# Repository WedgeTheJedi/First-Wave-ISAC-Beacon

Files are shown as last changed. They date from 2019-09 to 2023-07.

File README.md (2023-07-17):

# First-Wave-ISAC-Beacon
The First Wave ISAC Beacon is a recreation of the shoulder mounted radio worn by players in Tom Clancy's The Division video games. This version is modified from the 3D model work of 2 other authors (attributes in the guides).  It has fully functioning audio and visual effects from The Division 2. This version of the ISAC beacon also has multiple modes and features accessed by the buttons on the unit including:

- Startup boot sequence effect and audio
- 4 SHD skills from in-game with sound and visual effects
- World notifications as heard in-game that can be played manually, or automatically
- Dark Zone Mode that changes world notifications to ones specifically heard in the Dark Zone
- Rogue protocol - go rogue and turn the ISAC light ring RED while in the Dark Zone
- Volume control (especially to increase volume for cosplay at conventions)
- ISAC light ring 'chatter' effect when ISAC is talking

See the User Guide for information on how to access these features.

Here is a video showcasing the effects, however the camera doesn’t show the light ring effects as well as I had hoped (especially the light ring turning red during Rogue mode). 
https://vimeo.com/362583784

To achieve the effects of the First Wave ISAC Beacon, I designed and created a custom circuit board that simplifies assembly and soldering.  Also developed custom Arduino software to run the device and effects.  

See the Assembly Guide for a full list of parts and components as well as additional instructions and advice.

Latest updates:
2023-07-17 - Was working on building a few of these and found that the latest libraries and Arduino IDE compiler have improved performance.  This lead to timing issues with my older code which I believe I have fixed.  I also refactored a lot of the code including button state handling to be more precise and avoid the code treating a single click as multiple clicks.
             Known issue with current build: Rarely when you either enter or exit Rogue status the program will stop responding to further button clicks.  If this happens simply reboot the device, or add a but longer delay() at the end of the enter and exit Rogue functions.

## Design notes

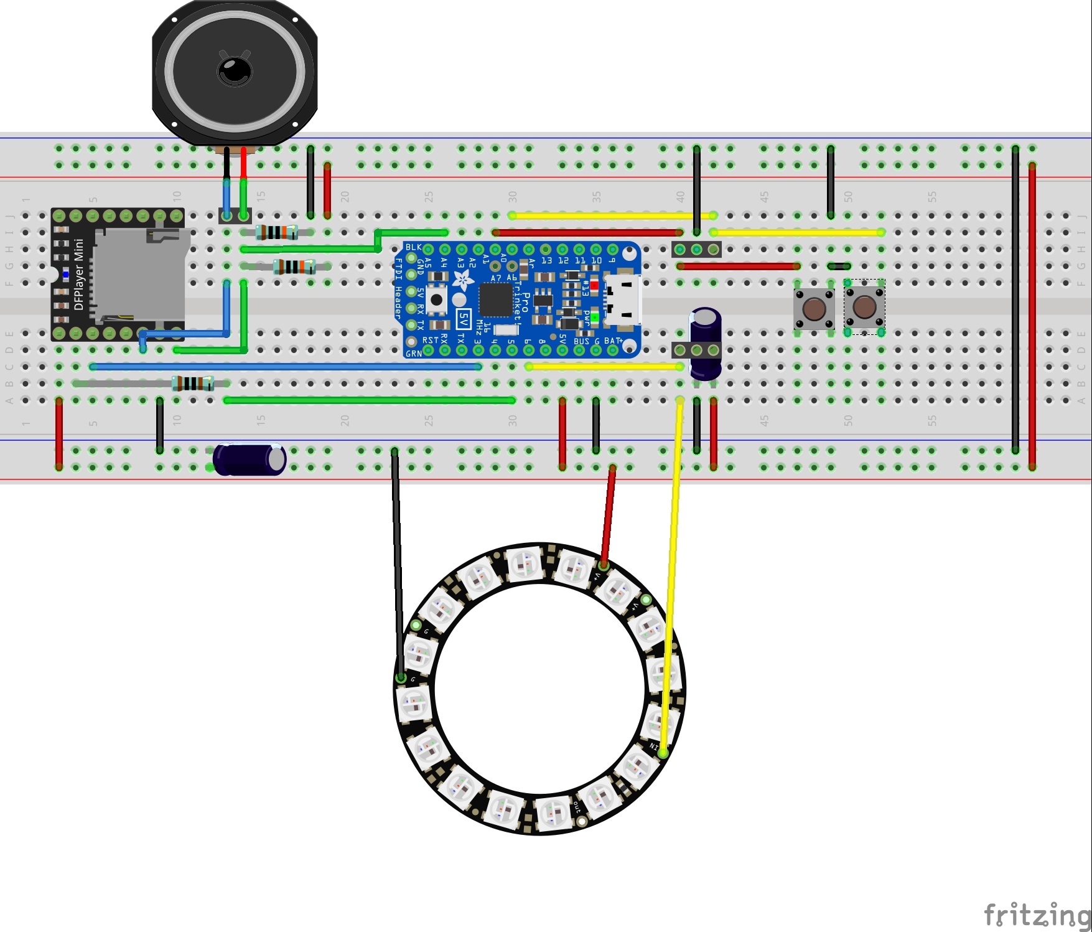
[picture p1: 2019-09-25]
PCB Files/FirstWaveISACBeacon_PCBv2.6_bb.jpg

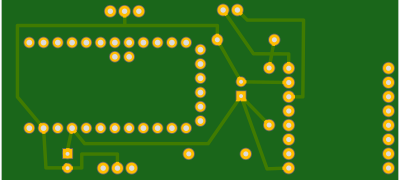
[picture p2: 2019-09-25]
PCB Files/PCB_Preview_Bottom.png

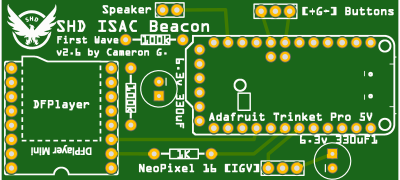
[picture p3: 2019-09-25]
PCB Files/PCB_Preview_top.png

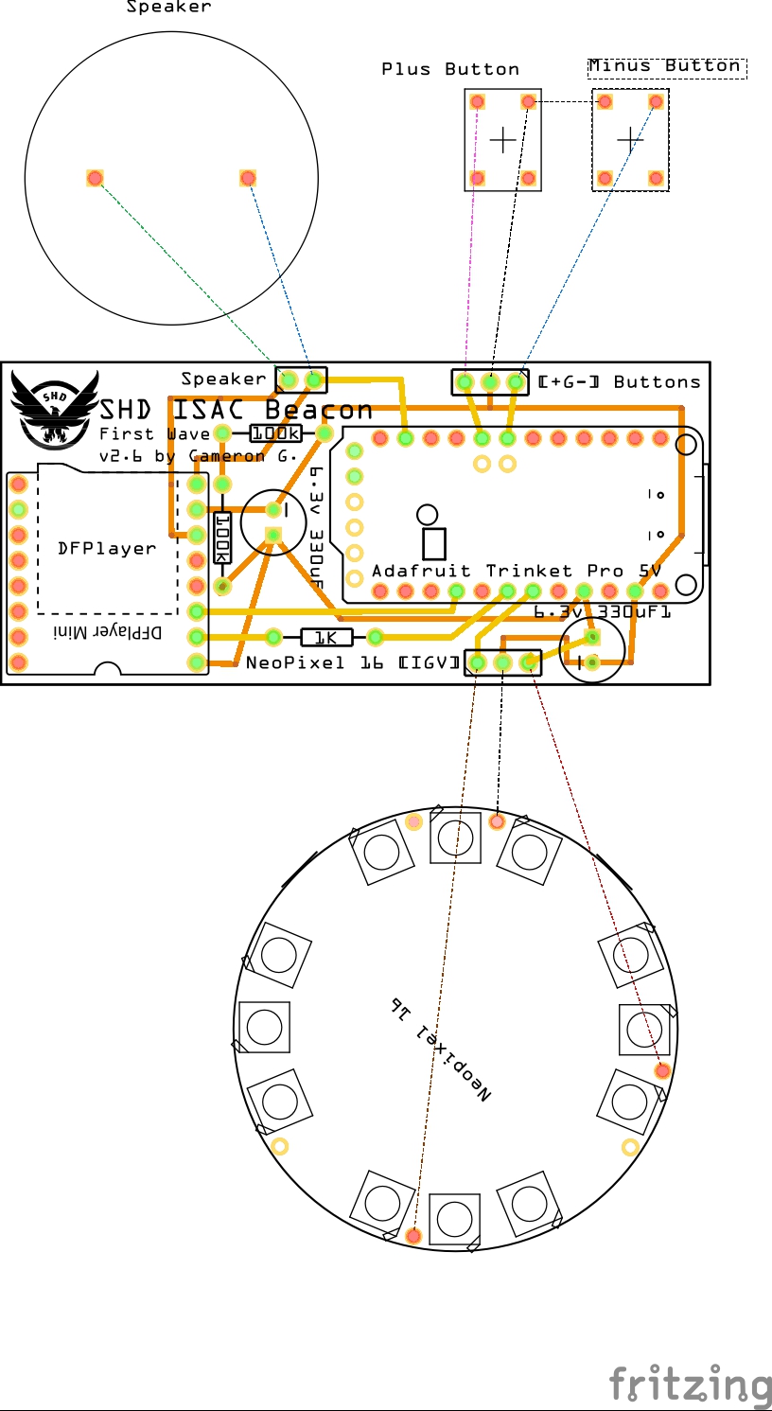
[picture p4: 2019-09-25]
PCB Files/FirstWaveISACBeacon_PCBv2.6_pcb.jpg

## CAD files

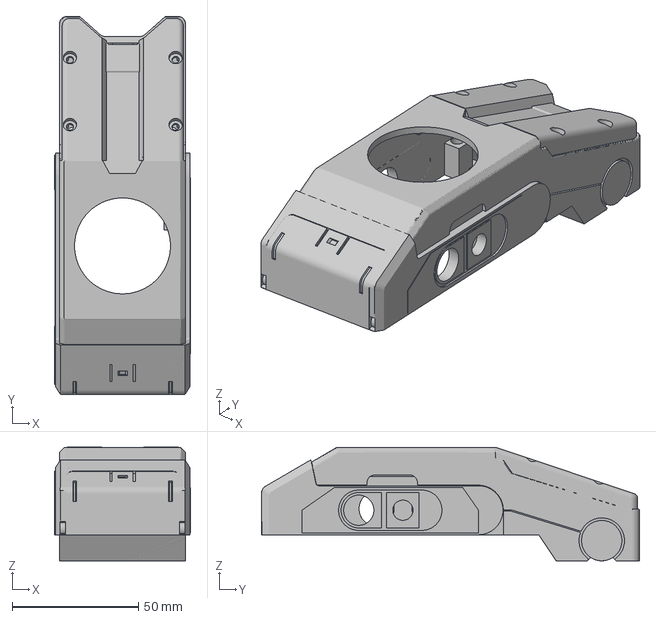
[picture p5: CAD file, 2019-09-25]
3D Print Files/FirstWave_Full_Frame.3mf
54.0 x 149.9 x 45.0 mm

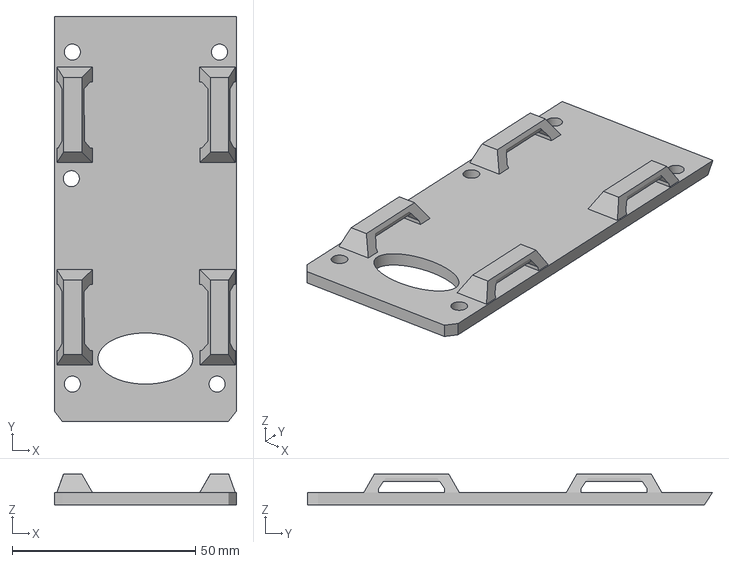
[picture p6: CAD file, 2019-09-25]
3D Print Files/FirstWave_Baseplate_w_Loops.3mf
49.7 x 110.4 x 8.39 mm

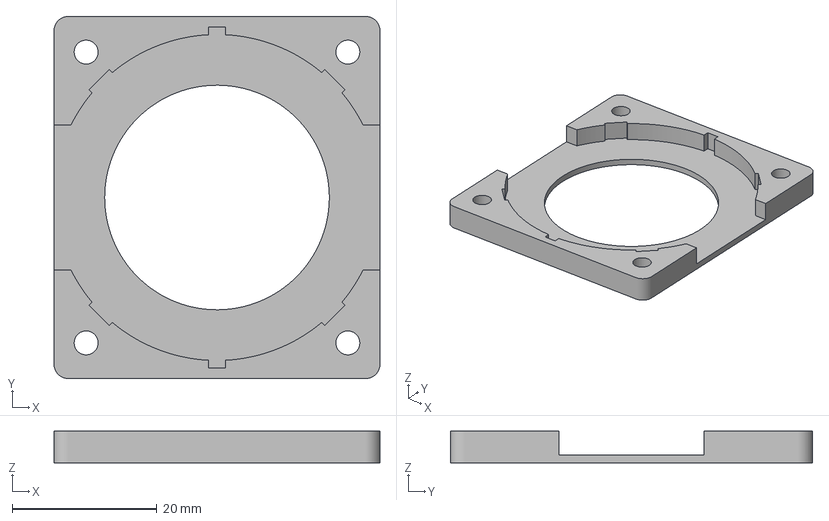
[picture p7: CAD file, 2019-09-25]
3D Print Files/FirstWave_Neopixel_Base.3mf
45.0 x 50.0 x 4.40 mm

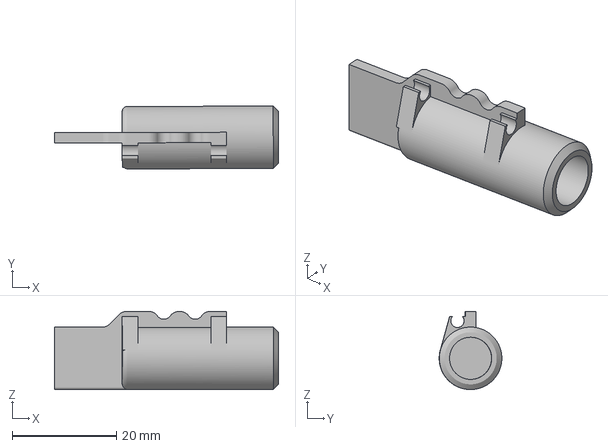
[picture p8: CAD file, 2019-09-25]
3D Print Files/FirstWave_Antenna_Bottom.3mf
43.0 x 12.0 x 15.0 mm

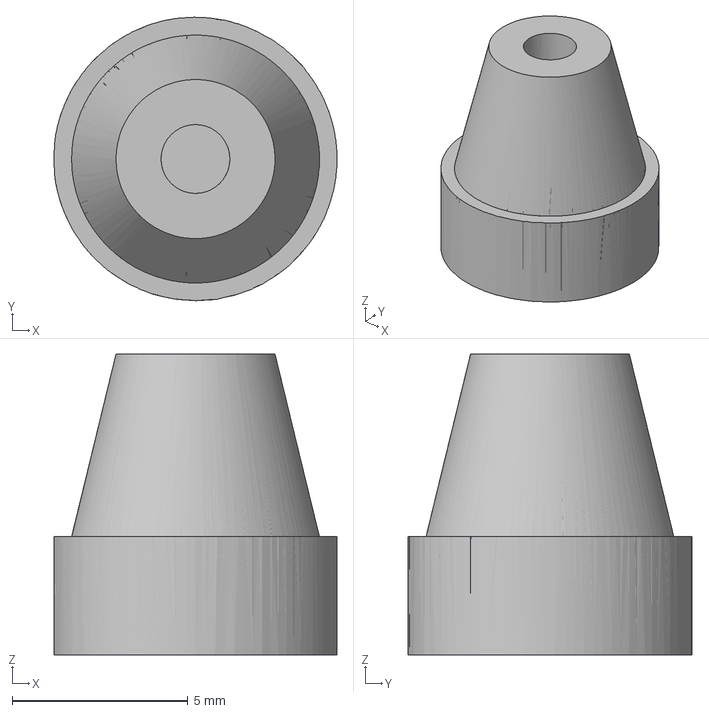
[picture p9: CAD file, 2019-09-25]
3D Print Files/FirstWave_CablePort.3mf
8.05 x 8.08 x 8.57 mm

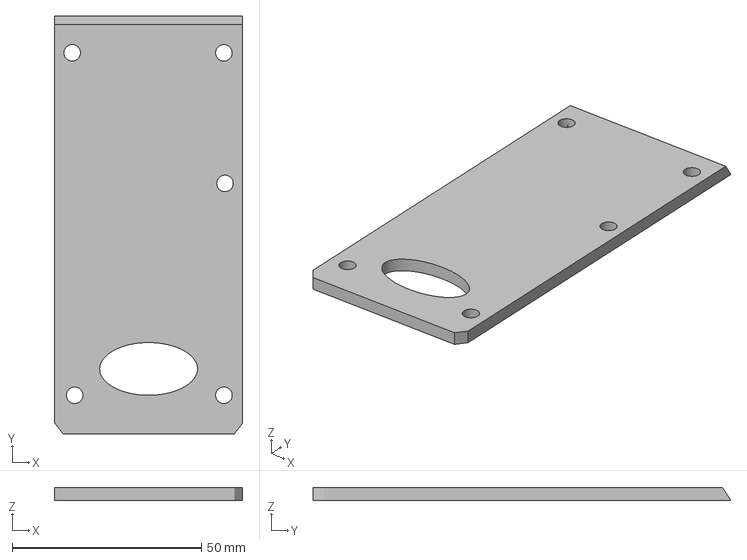
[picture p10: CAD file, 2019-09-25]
3D Print Files/FirstWave_Baseplate_w_Clip.3mf
49.7 x 110.4 x 3.39 mm

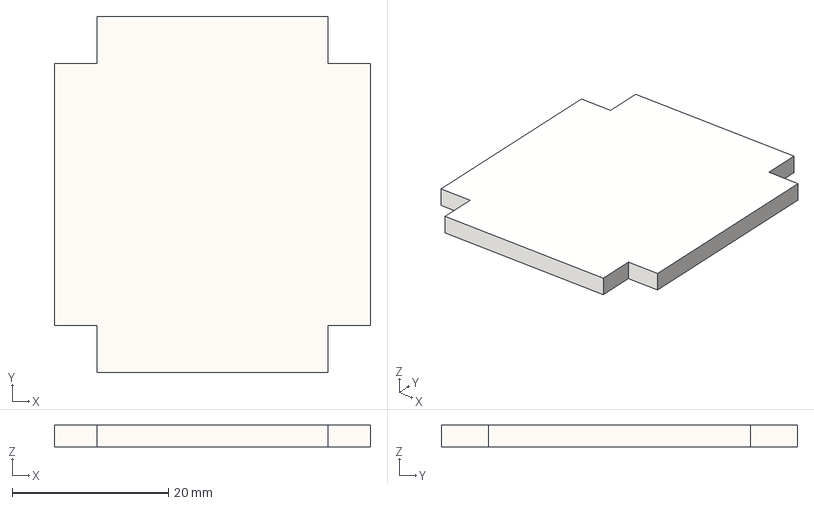
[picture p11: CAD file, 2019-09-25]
3D Print Files/FirstWave_LED_Difusser_Clear_Filament.3mf
40.4 x 45.5 x 2.80 mm

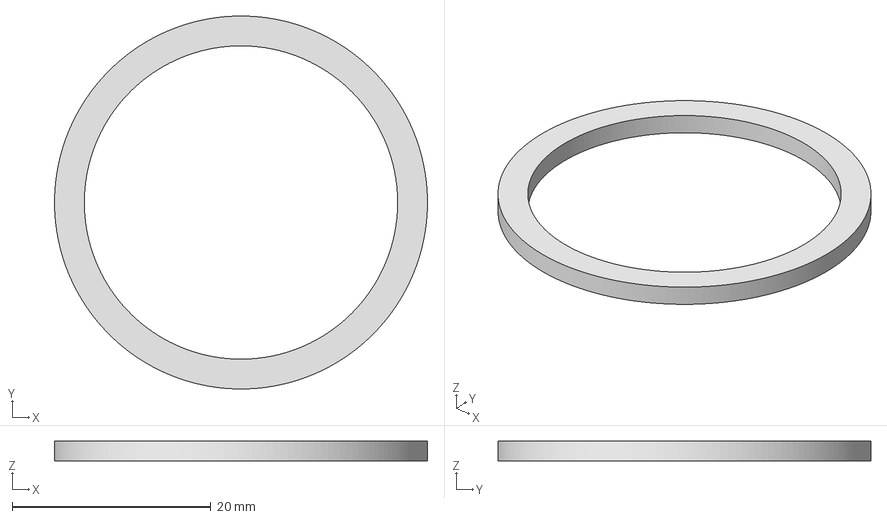
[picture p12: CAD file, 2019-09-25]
3D Print Files/FirstWave_LED_Ring_Clear_Filament.3mf
37.5 x 37.5 x 2.00 mm

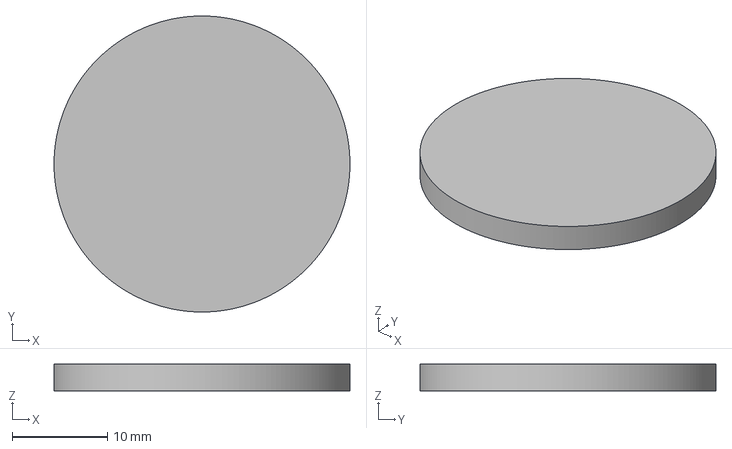
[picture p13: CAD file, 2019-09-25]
3D Print Files/FirstWave_LED_Ring_mid_Plate.3mf
31.0 x 31.0 x 2.80 mm

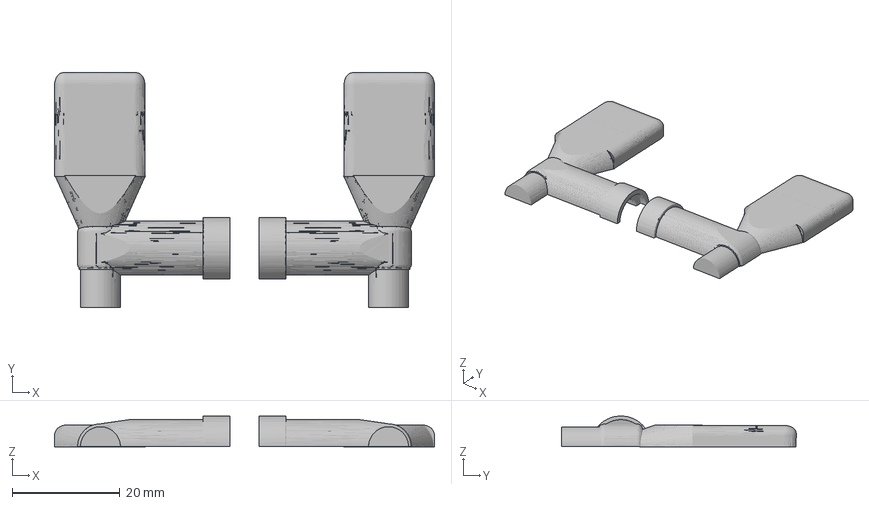
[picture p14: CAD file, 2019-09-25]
3D Print Files/FirstWave_Antenna_Frame_w_Bolt_Support.3mf
70.5 x 43.5 x 5.71 mm

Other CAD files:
3D Print Files/STLs/FirstWave_Antenna_Bottom.STL
3D Print Files/STLs/FirstWave_Antenna_Frame_w_Bolt_Support.stl
3D Print Files/STLs/FirstWave_Baseplate_w_Clip.stl
3D Print Files/STLs/FirstWave_Baseplate_w_Loops.stl
3D Print Files/STLs/FirstWave_CablePort.stl
3D Print Files/STLs/FirstWave_Full_Frame.stl
3D Print Files/STLs/FirstWave_LED_Difusser_Clear_Filament.STL
3D Print Files/STLs/FirstWave_LED_Ring_Clear_Filament.STL
3D Print Files/STLs/FirstWave_LED_Ring_mid_Plate.STL
3D Print Files/STLs/FirstWave_Neopixel_Base.stl

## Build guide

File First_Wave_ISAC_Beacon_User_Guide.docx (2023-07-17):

# First Wave ISAC Beacon User Guide

By Cameron G.

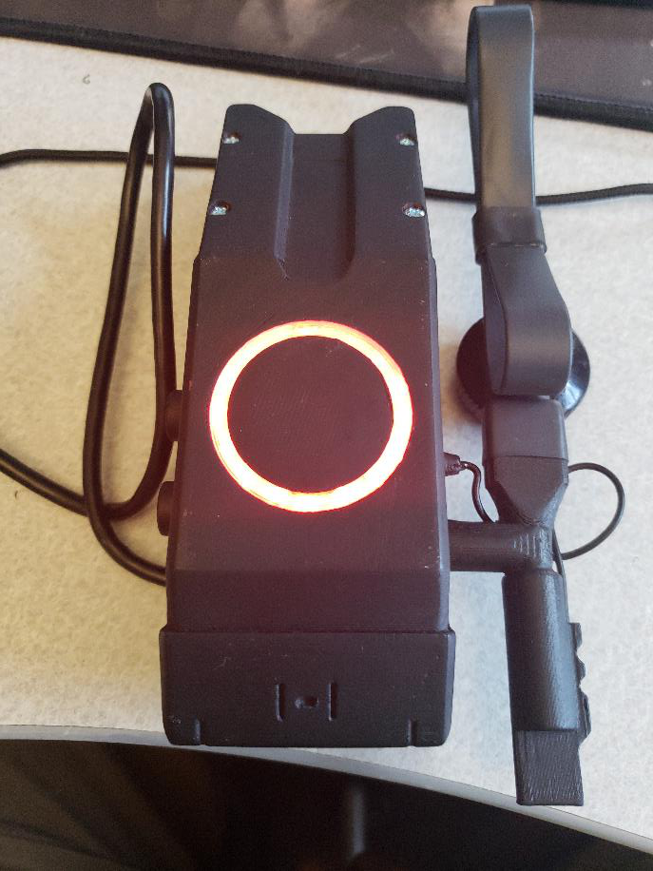
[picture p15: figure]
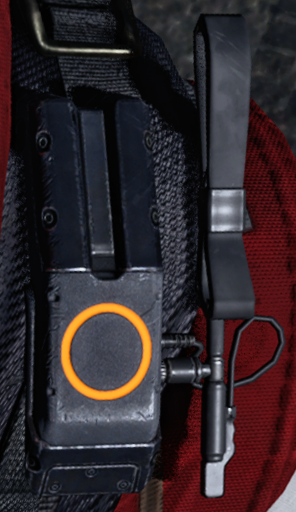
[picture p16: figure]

The following is a guide to using the First Wave ISAC Beacon which is a replica of the Integrated Systems Analytic Computer (ISAC) shoulder radio beacon used by SHD Agents in Tom Clancy’s: The Division franchise. The intended purpose of the First Wave ISAC Beacon is to give fans of The Division a way to show off their love of the game through Cosplay at conventions or just wearing it around for fun. Although it took a lot of time and effort to develop the software and circuitry used in the First Wave version of the ISAC beacon, I saw it as a challenge to do something fun and learn new skills along the way. I hope you enjoy and are excited about the result as I am.

-Cameron G.

# Acknowledgements

I followed the work done by two authors on thingiverse.com and their versions of the ISAC radio beacon. Building off the fine work they did, I created and modified specific parts to fit the functionality of this version and simplify the construction process. I also initially used some of the audio that was provided by a reddit user. I want to acknowledge their efforts and files that gave me a good starting point for my own version.

MZD471 (https://www.thingiverse.com/MZD471) - Tom Clancy's The Division Functional Comms Module (https://www.thingiverse.com/thing:1327053)
3D model used as the base of the First Wave version. Modified housing for buttons, shorter radio antenna, and edited to be one printed piece for the top and one separate piece for bottom.

guido666 (https://www.thingiverse.com/guido666) - The Division - Shoulder Beacon v3 (https://www.thingiverse.com/thing:1411233)
Parts of the 3D antenna were used to crate my own version and well as the code provided for learning how to work with the NeoPixel ring.

u/KlotziDotCom (https://www.reddit.com/user/KlotziDotCom/) - Hello Agents, here are some Division 2 ISAC Sound Files! (https://www.reddit.com/r/thedivision/comments/bwwdh8/hello_agents_here_are_some_division_2_isac_sound/)
Initial audio files I played with. I eventually recorded, edited, and normalized new audio files myself, but some of Klotzi’s work is still in the audio files used.

# Functionality and Controls

The ISAC beacon only has two buttons (+) and (-) on the left side. The following effects, modes, and functionality can be accessed by using these two buttons.

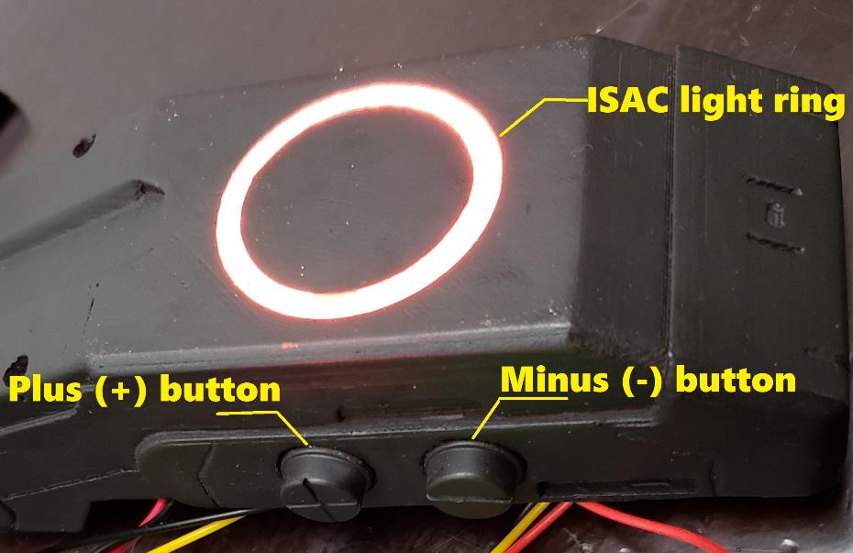
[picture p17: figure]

# Powering the ISAC beacon

The ISAC beacon is powered by the USB cable as outlined in the assembly instructions. Simply plug the ISAC beacon into a USB power adapter or portable phone charger that outputs 5V. The bootup on the control module takes a few seconds before the boot-up effect of the ISAC beacon begins to play.

Simply plug in the USB cable and then put the USB battery into the backpack the ISAC beacon is attached to. Some backpacks have headphone slots that you can use to have the USB cable go into the main compartment.

When you are done, simply unplug the USB cable from the power source. The device does not use a lot of power and you can easily get hours (if not days) of use out of a portable phone charger (depending on the size of the charger).

# Volume Control

To turn the volume up, hold the (+) button for a few seconds until the ISAC light ring turns green. Continue to hold the (+) button and the volume will increase in small steps with an audible tick and light up more LEDs. Release the (+) button when the volume is at your desired level, or the ISAC light ring is full green (max volume). If using as cosplay in a crowd or convention with a lot of noise, you will probably want to increase the volume. However, be cautious not to damage your hearing as it is closest to your own ears.

Similarly, to turn down the volume hold the (-) button for a few seconds and continue to hold until the desired volume level is reached.

# ISAC World Notifications

To manually activate a random ISAC notification, tap the (-) button once. Notification clips won’t duplicate until all clips have been played. While ISAC is talking, the ISAC light ring will change brightness based on ISAC’s voice to replicate the ‘chatter’ effect as seen in-game.

## Auto Notification mode

Auto Notification mode fires off the next ISAC notification clip every 60 seconds, this is great for walking around and getting notifications as if you were the in-game world. To turn on or off Auto Notification mode, tap the (-) button sequentially 2 times. If registered correctly you will hear one of two audio sound effects:

1. On – ISAC chirp (sound when mission objectives updated in-game)
2. Off – Drone cancelation (self-destruct sound)

If after tapping the (-) button twice you don’t hear one of the above sound effects but instead get an ISAC Notification affect, try again making sure that your sequential taps are less than a half second apart.

# Activating SHD Skills

The First Wave ISAC beacon is programmed with 4 effects found in the Division 2:

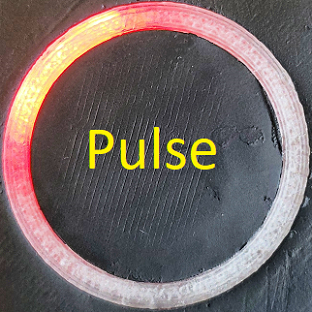
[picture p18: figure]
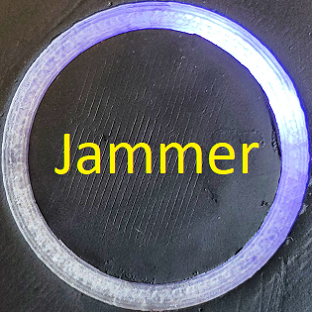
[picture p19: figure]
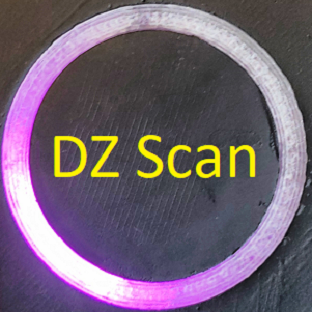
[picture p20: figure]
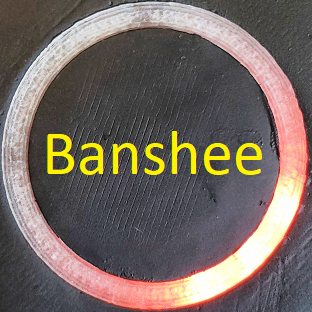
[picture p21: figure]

To activate a skill, tap the (+) button once. After a moment, the currently selected skill will activate. To cycle between the skills, sequentially tap the (+) button before the effect activates. The ISAC ring will light up one corner with the corresponding color of the skill as shown above. The color that is displayed on the ISAC ring after the last (+) button tap will be the skill that activates.

If you want to re-activate the same skill, simply tap the (+) button once and the skills will not cycle.

Note: the red colored LEDs during the pulse skill indicate detected hostiles in that direction.

# Entering the Dark Zone

Dark Zone mode changes the ISAC notifications and allows you to become a rogue agent. To enter or exit the Dark Zone, press and hold both the (+) and (-) buttons for a few seconds until you hear ISAC confirm you have entered or exited the Dark Zone.

ISAC notifications in Dark Zone mode are specific to audio only found in the Dark Zone. One of those is the extraction effect of calling in a chopper. When this effect fires, it will continue to play the audio clips of an extraction sequence every 15 seconds until the extraction is complete. This happens regardless of if you exit the Dark Zone or activate other notifications / effects.

## Rogue Protocol

While in the Dark Zone you can also go rogue, which turns the ISAC ring red. To go rogue, tap (not hold) both the (+) and (-) buttons at the same time while in Dark Zone mode. To exit rogue, tap the (+) and (-) buttons again.

# FAQ

## Q: Are you going to continue to release updates?

A: Probably, as I have time. I would like to and I’m very proud of the work and effort that went into making this project, especially the technical coding and circuitry. I have posted the code and files on GitHub (https://github.com/WedgeTheJedi/First-Wave-ISAC-Beacon) so that others can also contribute or make recommendations / suggestions. I didn’t just make this for me, I made it for others who want to make one themselves.

## Q: Can I order one? How much?

A: Unfortunately, I can’t accommodate orders or requests for the First Wave ISAC Beacon for the following reasons:

1. I have a full-time job and other responsibilities that prevent me from being able to make or deliver these in a timely manner. I did it as an educational and fun project.
2. The 3D models that I started with and modified were from other authors, using their work to make a profit and not properly compensating them would be inappropriate, disrespectful, and is prohibited by their use agreements.

If there is enough demand to build these, I’ll look at ordering a large batch of the custom circuit board to provide to those building their own, but I would not be able to provide the 3D models. I have provided all of the files to order your own circuit boards using my design (seen below). I have also included links to all parts used in the assembly instructions so you should have what you need to order your own parts.

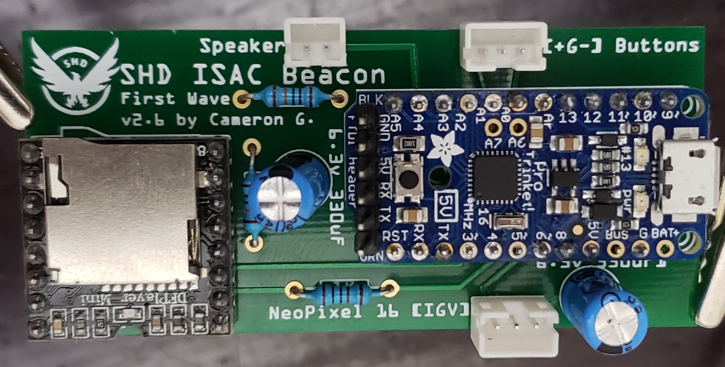
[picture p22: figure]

Q: Can I fly with this on my backpack, or will it be confiscated at airport security?

A: I can’t guarantee what the TSA or equivalent airport security personnel will do in your case. However, I did take my prototype ISAC beacon on my backpack through security without incident. As required, I put my backpack through the security scanner with all carry-on luggage and they did not ask any questions about it. They may ask you to power the device as they have with other electronics I have brought through screening in the past, so make sure you can turn it on for them and show them a few of its effects. If you are concerned, you should either leave it at home or place it into your checked baggage with a note that it is a costume prop that makes sound and light effects.

I did take it also into a theme park that required going through security screening as well as a bag check. They were much more curious about it and had multiple security personnel inspect the device and ask me about it. I simply explained that it was a toy that I made to make some light effects and sound effects from a video game I like to play. After they had me open it up and asked a few more questions they let me through. However, the process took some time and I decided that rather than cause a long wait for others in the security line or to possibly cause other concerns at the park I took it off my bag for the remainder of my visit.

# Updates and Known Issues

July 17, 2023

Known Issue: Rarely when you either enter or exit Rogue status the program will stop responding to further button clicks. If this happens simply reboot the device, if you have access to compile the code, you can also try and increase the delay time at the end of the enter and exit Rogue functions.

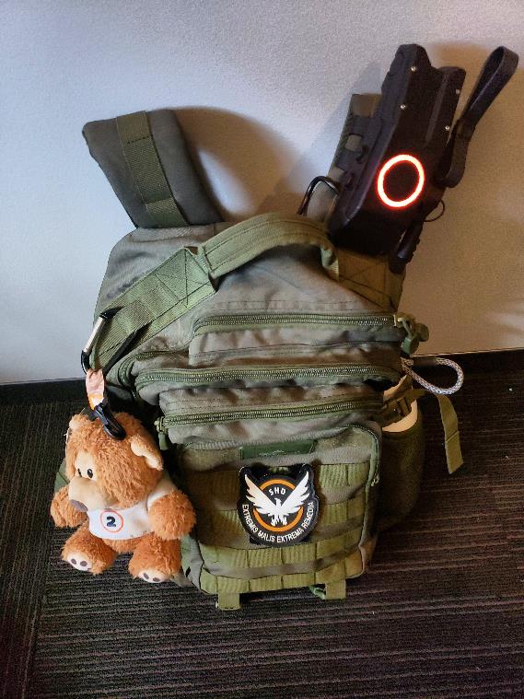
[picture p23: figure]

First Wave ISAC Beacon User Guide

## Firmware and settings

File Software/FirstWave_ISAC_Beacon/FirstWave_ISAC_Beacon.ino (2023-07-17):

/*********************SUMMARY AND ACKNOWLEDGEMENTS*********************
   The following code is designed for use with the Arduino
   setup of the First Wave ISAC Beacon by Cameron Goodwin.
   This code uses example code from the following sources
   and I wish to acknowledge and thank those authors for
   their examples and hard work.

   Guido666 - Initial Neopixel code from their version of
              the beacon and parts of their 3D models that
               I modified for my version.
              https://www.thingiverse.com/guido666/about
              https://www.thingiverse.com/thing:1411233

   MZD471 -   3D models and housing that I used for the
              beacon itself making a few slight modifications
              to the antenna assembly and adding holes for
              buttons on the side of the beacon.
              https://www.thingiverse.com/MZD471/about
              https://www.thingiverse.com/thing:1327053

   Angelo
   Qiao -     The example code for the DFMini Player
              library.  Legal and troubleshooting
              notices from their sample are below.
              Angelo.qiao@dfrobot.com

              /*********************************************************
                DFPlayer - A Mini MP3 Player For Arduino
                <https://www.dfrobot.com/index.php?route=product/product&product_id=1121>

               ***************************************************
                This example shows the basic function of library for DFPlayer.

                Created 2016-12-07
                By [Angelo qiao](Angelo.qiao@dfrobot.com)

                GNU Lesser General Public License.
                See <http://www.gnu.org/licenses/> for details.
                All above must be included in any redistribution
               ****************************************************

               ***********Notice and Trouble shooting***************
                1.Connection and Diagram can be found here
                <https://www.dfrobot.com/wiki/index.php/DFPlayer_Mini_SKU:DFR0299#Connection_Diagram>
                2.This code is tested on Arduino Uno, Leonardo, Mega boards.
               ****************************************************/
/*******************END SUMMARY AND ACKNOWLEDGEMENTS*******************/

///////////////////////////////////////
//  List of Improvements / Things to do
///////////////////////////////////////

/*  
    Although I put a lot of effort and work into creating a great software package to go with
    the First Wave ISAC Beacon, I reached a point where I needed to stop and make an initial
    release.  This meant that some other cool effects or ideas I had needed to be put off
    until another time.  I welcome any feedback and conributions to the codebase through
    the Github project.  Here is a list of features / improvements that I currently have:

    -   Make the flare fire off with a specific button press like 3 taps rather than just be part
        of the random chatter.
    -   Add in an effect mode where the Halo does some things so it isn't just a constant color
        for if you were walking around a convention or something so it is more 'flashy' and eye
        catching.  Something similar to the throbbing or effects in Guido666's code possibly.

    Update July 16, 2023
    I was building a few more beacon circuts and after downloading the latest Arduino IDE, found
    that improvements to the compiler and libraries appear to have changed some of the timing when
    run on the circuit.  That resulted in some bugs, especially where entering / exiting Rogue
    Mode would make the circuit stop responding.  I believe I have now fixed this and also fixed
    up the button input detection so that it is now cleaner.
*/

#include "Arduino.h"
#include "SoftwareSerial.h"
#include "DFRobotDFPlayerMini.h"
#include <Adafruit_NeoPixel.h>
#include <math.h>

/////////////////////////////////////////////////////////
//  DFPlayer Mini Configuration
//      Used to play all audio and sound clips
/////////////////////////////////////////////////////////
DFRobotDFPlayerMini _DFPlayer;

//  This initializes the ~3 and ~5 digital pins for a serial connection
//  port we use to control the DFPlayer Mini
SoftwareSerial _DFPlayerSerial(DD3, DD5);  // RX, TX

//  Global variables and constants used for audio control
#define VOLUME_MAX       30   // DFPlayer Max volume is 30
#define VOLUME_STEP      2    // Value change of volume each step
#define VOLUME_STEP_WAIT 200  // Milliseconds between steps

uint8_t _AudioVolume      = 20;    // Start volume at ~70% of 30
uint32_t LastVolumeChange = 0;


//  Provided from the DFPlayer Mini example code, is useful for
//  debugging
void DFDebugPrintDetail(uint8_t type, int value);

//  The way the DFPlayer Mini works is that the global # of a track is
//  determined by listing the files as they were phsyically coppied onto
//  the SD card.  For example, re-copying the first file to the card will
//  change its order in global #'s and it will now be last
//  This enum should correspond to each sfx's global ID in order as they
//  should be copied to the SD in the setup instructions.
enum SoundEffects {
  // Startup Sequence
  Div2Startup = 1,
  Div2LoadingTics,
  BootUp,
  ISACReactivated,
  ISACReactivatedAgentAuthenticated,

  // Skills
  DZScanAudio,
  PulseAudio,
  BansheeAudio,
  JammerAudio,

  // DarkZone
  EnteringDarkZone,
  ExitingDarkZone,
  RogueProtocol,
  RogueProtocol_SFX,
  RogueStatusRemoved,
  RogueStatusRemoved_SFX,
  HeloGalExtractionCalled,
  HeloGalAlmostAtExtractionZone,
  HeloGalArrived,
  HeloGal30seconds,
  HeloGal15Seconds,
  HeloGalReturningToBase,

  // World Chatter
  VitalSignsCritical,
  AgentVitalSignsZero,
  FriendlyControlPointNearby,
  AgentRequestingBackup,
  CiviliansInDanger,
  DetectedNearbyLocationGuardedByHostiles,
  DrinkingWaterNearby,
  HostileControlPointIdentified,
  HostileRadioIntercepted,
  IncomingHostilesDetected,
  ObjectOfInterestDetected,
  RationsNearby,
  SuppliesDetected,

  // Dark Zone Chatter
  AgentOutOfAction,
  ImmediateMedicalAssistanceNeeded,
  DZLandmarkEngaged,
  DZContaminatedGearDetected,
  DZDropIncoming,
  DZDropStolen,
  NearbyAgentDissavowed,
  RogueAgentNearby,
  RogueAgentEliminated,

  //  Mode and other util sounds
  BackupNotificationBeeps,
  SkillCancel,
  Chirp,
  Div2SingleTic,

  // End enum - this can be used as a variable to know how many total clips we have
  ISACAudioCount
};

//  These will be used to randomly fill an array with the random
//  clips for world and DZ chatter.  This way each clip gets played
//  before one of them repeats, but it will still be in a random order
#define DZ_CLIPS_START  AgentOutOfAction
#define DZ_CLIPS_END    RogueAgentEliminated
#define DZ_CLIPS_COUNT  DZ_CLIPS_END - DZ_CLIPS_START + 2  // +2 because we need one more spot for the Extraction effect
                                                           // in the array so it can be fired off with the other effects
uint8_t DZClipOrderArray[DZ_CLIPS_COUNT] = {};
uint8_t CurrentDZClip = 0;

#define CHATTER_CLIPS_START VitalSignsCritical
#define CHATTER_CLIPS_END SuppliesDetected
#define CHATTER_CLIPS_COUNT CHATTER_CLIPS_END - CHATTER_CLIPS_START + 1

uint8_t ChatterClipOrderArray[CHATTER_CLIPS_COUNT] = {};
uint8_t CurrentChatterClip = 0;

//////////////////////////////////////////////////////
//  Side button (+) and (-) config
//////////////////////////////////////////////////////

//  The Pins that our + and - external buttons on the beacon are hooked up to
//  We are using analog pins here, but could also use digital pins.
#define MINUS_BUTTON_PIN A1
#define PLUS_BUTTON_PIN  A0

uint8_t MinusButtonLastState = HIGH;
uint8_t PlusButtonLastState = HIGH;

//  These are used to help keep rack of the button press
//  functionality where we are watching for both sequential
//  tapping and holding of each button or both together.
//  As mentioned in the things to imrpove, this could be
//  simplified more than likely.
bool MinusButtonActionCleared     = true;   // Helps prevent double hits on buttons
bool PlusButtonActionCleared      = true;
bool MinusButtonIgnoreNextRelease = false;  //  Used when we are holding so we
bool PlusButtonIgnoreNextRelease  = false;  //  don't fire off an event on release
bool MinusButtonReleaseHandled    = true;   // Helps ensure we handle button releases properly
bool PlusButtonReleaseHandled     = true;   // and don't double hit our logic code
bool ComboButtonActionCleared     = true;
bool ComboButtonReleaseHandled    = true;
bool IgnoreSingleButtonHold       = false;
uint8_t MinusButtonTimesTapped    = 0;
uint8_t PlusButtonTimesTapped     = 0;
uint32_t LastInputCycle           = 0;
uint32_t MinusButtonHeldSince     = 0;      // when the button was pressed but not yet
uint32_t PlusButtonHeldSince      = 0;      // released
uint32_t MinusButtonReleased      = 0;      // These help to watch for sequential taps and time out
uint32_t PlusButtonReleased       = 0;      // when to fire off an effect after tapping has finished

/////////////////////////////////////////////////////////
//  NeoPixel 16 config (aka the beacon's halo)
/////////////////////////////////////////////////////////
#define LED_COUNT     16    // Number of LEDs on the NeoPixel
#define NEOPIXEL_PIN  6     // Data pin for neopixel
#define CHATTER_PIN   A4    // Analog pin used to detect talking volume for
                            // the chatter blinking effect

Adafruit_NeoPixel Pixels = Adafruit_NeoPixel(LED_COUNT, NEOPIXEL_PIN);

#define DEFAULT_BRIGHTNESS 85
#define CHATTER_BRIGHT_MAX 150
#define CHATTER_BRIGHTNESS 45  // Brightness to go to as the base
                               // when Isac is talking

uint16_t HighestChatterLevel = 0;

//  Helper functions with setting the pixel's colors or resetting them
void ResetPixels();
void ResetPixels(uint32_t Color);
void ResetPixels(uint32_t Color, uint8_t Brightness);
void SparklePixels(uint32_t EffectLength, uint32_t SparkleColor, uint8_t Brightness);
void SparklePixels(uint32_t EffectLength, uint32_t SparkleColor, uint8_t Brightness, uint32_t BaseColor);
void SparklePixels(uint32_t EffectLength, uint32_t SparkleColor, uint8_t Brightness, uint32_t BaseColor, uint8_t Delay);
void UpdatePixelsFromArray(uint32_t HaloArray[], size_t ArraySize);
void UpdatePixelsFromArray(uint32_t HaloArray[], size_t ArraySize, uint8_t Brightness);

////////////////////////////////////////////////////////////
//  Pre-defined Colors used for effects and such
////////////////////////////////////////////////////////////
#define COLOR_RED    0xFF0000
#define COLOR_GREEN  0x00FF00
#define COLOR_BLUE   0x0000FF

//  True SHD 'Division' Orange is (255, 109, 16), but on the
//  Neopixel 16 this looks too yellow and not orange ehough
#define COLOR_SHD    0xFF6D10

//  These are custom color shades that look better on the
//  Neopixel in terms of SHD orange when being displayed
#define COLOR_SHD_CUSTOM        0xFF4C00       //  This one is still more 'yellow' but is good for some effects
#define COLOR_SHD_CUSTOM_DARK   0XFF2A00       //  This seems to be the best represntation of orange on the Neopixel
                                               //  and is a darker version of SHDCustom, since this looks best this
                                               //  is the default halo color

//  Other colors used by skills
#define COLOR_DZ_SCAN           0xe500e5
#define COLOR_BANSHEE_WAVE      0x69aaff
#define COLOR_JAMMER_CHARGE     0x3030ff
#define COLOR_JAMMER_DISCHARGE  0x5055ff

//  These are used for convenience during debugging to change default color
//  scheme with changing one variable rather than all over the code base.
#define COLOR_DEFAULT      COLOR_SHD_CUSTOM_DARK
#define COLOR_DEFAULT_DARK COLOR_SHD_CUSTOM_DARK

/////////////////////////////////////////////////////////////////////
//  Global state variables that are used across loop function cycles
/////////////////////////////////////////////////////////////////////
uint32_t _CurrentPixelColor = COLOR_DEFAULT;  // Current color... start orange

bool _IsRogue            = false;
bool _IsInDarkZone       = false;
bool _IsExtractionCalled = false;
uint8_t _ExtractionPhase;
uint32_t _ExtractionLastEvent = 0;
uint32_t _ChatterThreshold;  // Value that if the analog pin is higher, does the
                             // the chatter effect halo blinking

//  This enum is used to set the order of the skills and
//  how the skill wheel will cycle between them in order
enum Skills {
  Pulse,    // Red
  Jammer,   // Blue
  Banshee,  // Orange
  DZScan,   // Purple
  SkillCount
};

uint8_t _CurrentSkill = Pulse;       // used to cycle the skill powers

enum EffectMode {
  Manual = 0,
  Auto,
  EffectModeCount  // used as variable to know when we have cycled all the
                   // modes and need to loop back to the first
};

#define AUTO_EFFECT_DELAY 60000  // 1 minutes between auto audio effects
uint8_t _CurrentEffectMode = Manual;  // used to cycle between functionality modes
uint32_t _LastEffectTime = 0;

///////////////////////////////////////////////////////////////////
//  Initial Start-up and continuous looping functions
///////////////////////////////////////////////////////////////////
void setup() 
{
  //  Serial port for debug output (you will need an FTDI cable if
  //  running on the Trinket Pro 5V)
  Serial.begin(115200);

  //  Initialize the Neopixel / halo
  Pixels.begin();
  Pixels.setBrightness(DEFAULT_BRIGHTNESS);
  _LastEffectTime = millis();

  // Initialize the button and chatter pins as input.  Since we are 
  // not using a drawresister these will be INPUT_PULLUP
  pinMode(MINUS_BUTTON_PIN, INPUT_PULLUP);
  pinMode(PLUS_BUTTON_PIN, INPUT_PULLUP);
  pinMode(CHATTER_PIN, INPUT_PULLUP);

  Serial.println();
  Serial.println(F("Initializing DFPlayer ... (May take 3~5 seconds)"));

  //  Serial port to control the DFMini Player (must be 9600)
  _DFPlayerSerial.begin(9600);

  if (!_DFPlayer.begin(_DFPlayerSerial)) 
  {  
    //Use softwareSerial to communicate with mp3.
    Serial.println(F("Unable to begin:"));
    Serial.println(F("1.Please recheck the connection!"));
    Serial.println(F("2.Please insert the SD card!"));
    digitalWrite(LED_BUILTIN, HIGH);  // turn the LED on (HIGH is the voltage level)
    while (!_DFPlayer.begin(_DFPlayerSerial))
    {
      delay(250);
    };
  }
  Serial.println(F("DFPlayer Mini online."));

  //  Seed our random number generator
  int seed = millis();
  srand(seed);

  //  Initialize the world and DZ chatter arrays
  for (uint8_t i = 0; i < CHATTER_CLIPS_COUNT; i++) 
  {
    ChatterClipOrderArray[i] = CHATTER_CLIPS_START + i;
  }

  ShuffleArray(ChatterClipOrderArray, CHATTER_CLIPS_COUNT);

  //  this sets the Extraction event into the DZ chatter
  //  effects to be fired
  DZClipOrderArray[0] = HeloGalExtractionCalled;

  //  Fill the other spaces in the array with the other DZ Chatter
  //  effects.
  for (uint8_t i = 1; i < DZ_CLIPS_COUNT; i++) 
  {
    DZClipOrderArray[i] = DZ_CLIPS_START + i - 1;
  }

  ShuffleArray(DZClipOrderArray, DZ_CLIPS_COUNT);

  _DFPlayer.volume(_AudioVolume);  //Set volume value. From 0 to 30

  //  Initialize Boot-up effect
  BootUpEffect();
}
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

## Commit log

2019-09-25 Initial commit of all files
    Initial upload of the first version of the First Wave ISAC Beacon files and instructions
    [FirstWaveISACBeacon_PCBv2.6.fzz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]
2023-07-17 Updates to address issues with latest compiler optimizations and button detection logic
    [FirstWave_ISAC_Beacon.ino]
